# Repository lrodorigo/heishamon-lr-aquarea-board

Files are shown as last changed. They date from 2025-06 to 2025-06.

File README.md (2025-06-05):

# HeishaMon Aquarea
### Alternative Galvanically Isolated Design
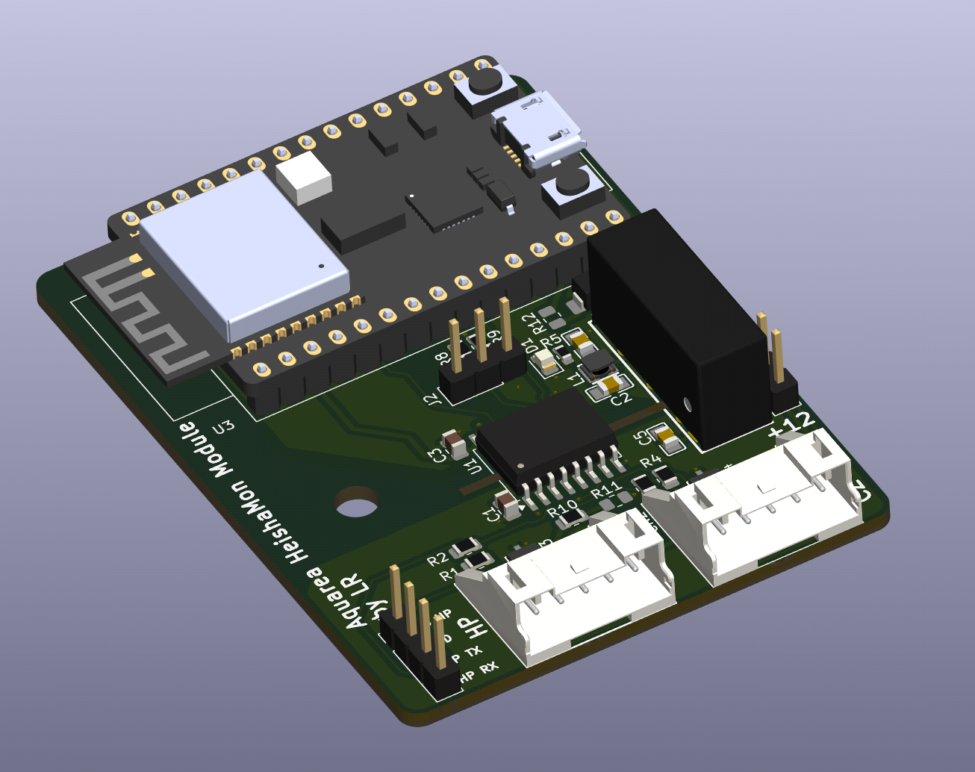
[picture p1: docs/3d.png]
Board Preview


This repository contains an alternative schematic for integrating with Panasonic Aquarea heat pumps using the **HeishaMon** firmware.

## ⚠️ Disclaimer

> This design is **experimental** and has **not yet been tested**.  
> The first hardware version is expected to arrive within a few days.  
> Use at your own risk and feel free to open issues or discussions for feedback and improvements.

## 🛠️ Key Features

- **Galvanically isolated design**  
  Ensures complete electrical isolation from the heat pump for improved safety and reliability.

- **Based on ESP32-C3-DevKitC-02 (official Espressif dev module)**
   
- **Flexible power supply configuration**  
  The board is designed to support different power input scenarios for testing.  
  By default, it uses **12V @ 250mA** to ensure higher available power and better stability.

## 🔧 Firmware Notes

> This board uses different GPIOs than the original HeishaMon design.  
> You **will need to modify the `#define` values** in the firmware source accordingly to match this schematic.  

## 🧩 Usage

The design is tailored for experimenting with various supply options and integration methods, while maintaining full galvanic isolation of the communication lines with the heat pump.

## 📁 Contents

- `export/`: The gerber files

## 📌 Notes

- Intended to be used with HeishaMon firmware (see: https://github.com/Egyras/HeishaMon/)
- Verify jumper settings and isolation components before connecting to the heat pump.

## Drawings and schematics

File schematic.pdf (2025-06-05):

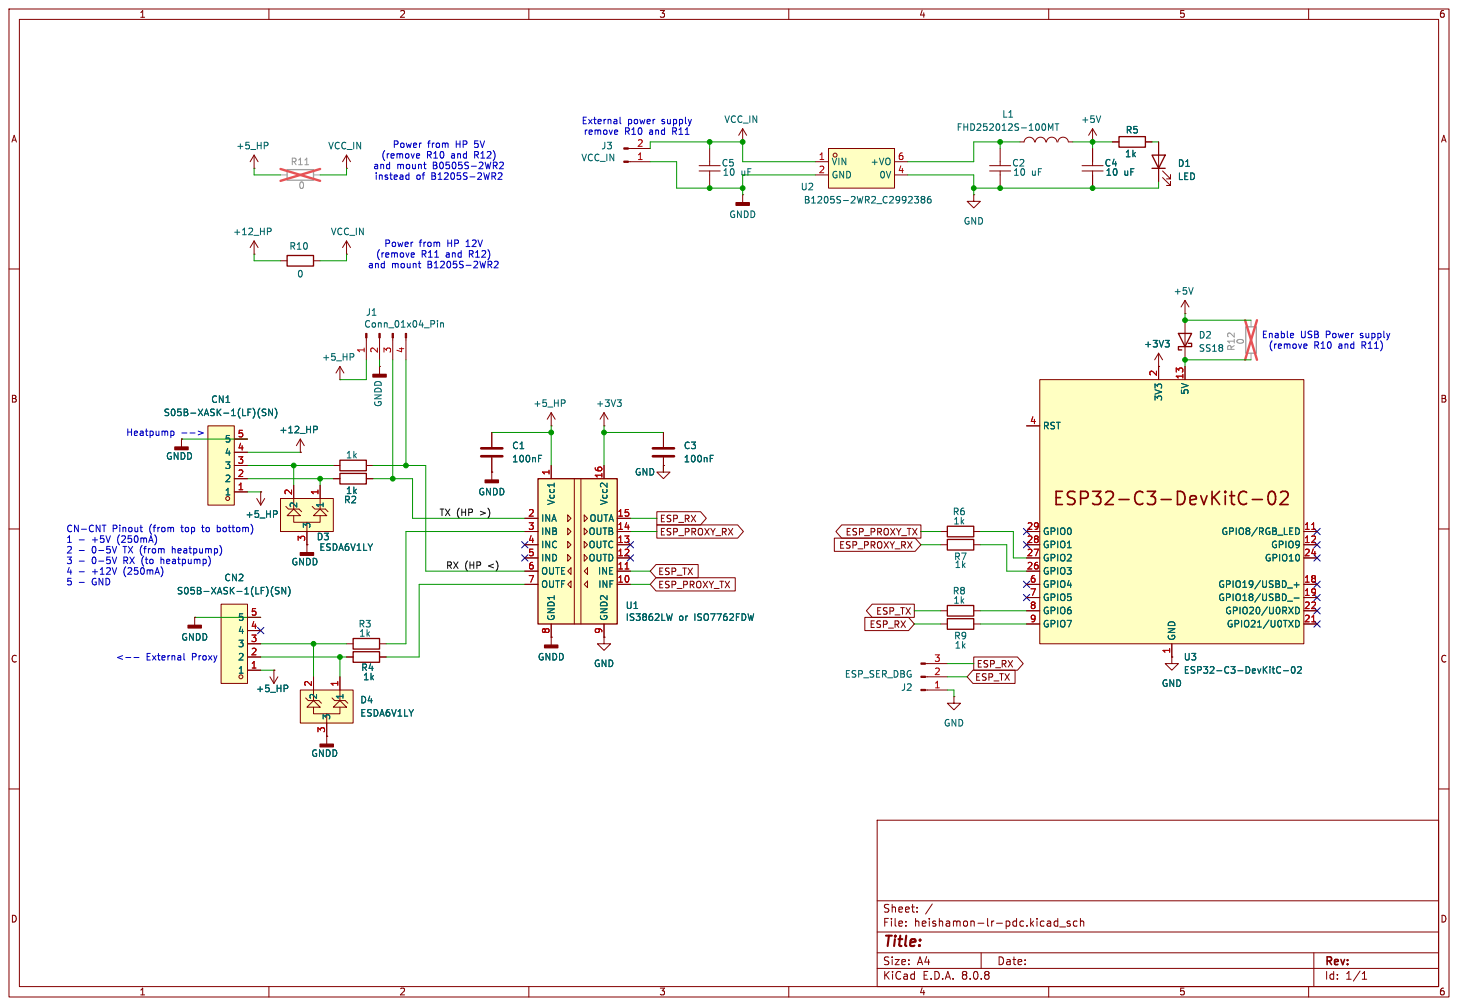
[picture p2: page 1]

(remove R10 and R12) and mount B0505S-2WR2
instead of B1205S-2WR2 Power from HP 12V

5 CN1 S05B-XASK-1(LF)(SN) GNDD

INE 11 OUTD 12 OUTC 13 OUTB 14 OUTA 15 Vcc2 16

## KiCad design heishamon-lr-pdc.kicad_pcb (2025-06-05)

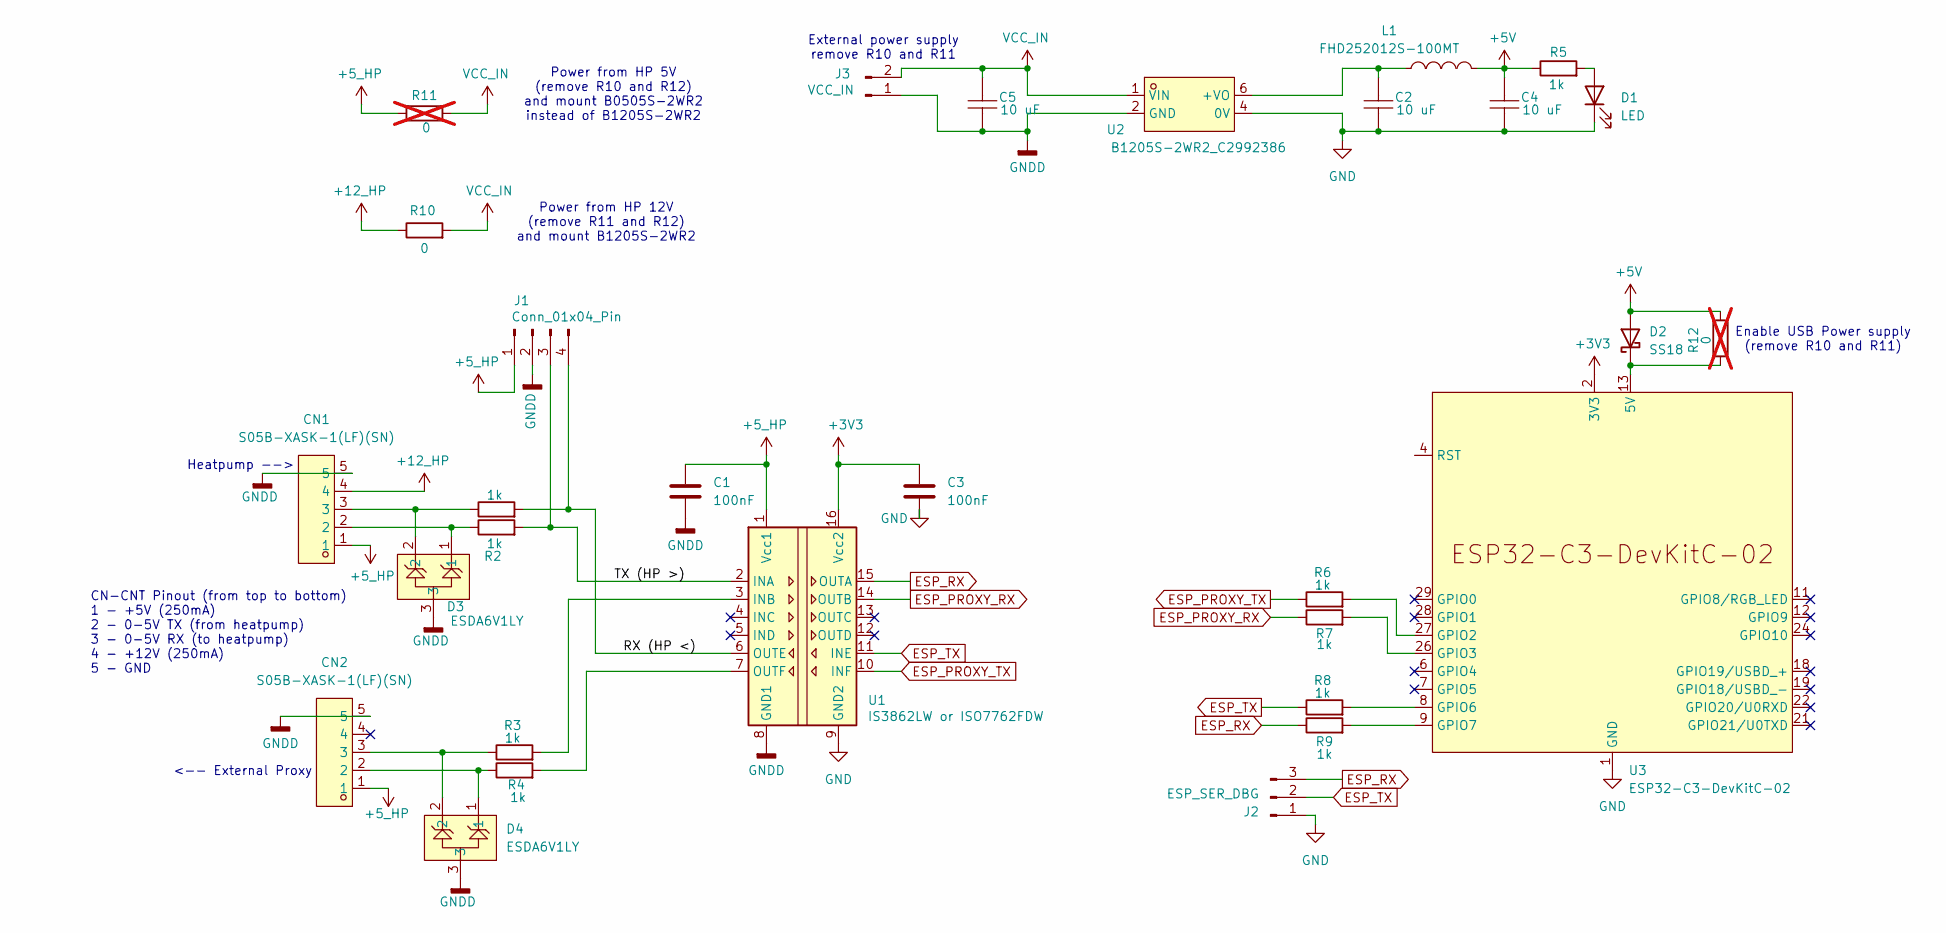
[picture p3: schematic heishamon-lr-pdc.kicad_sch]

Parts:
C1, C3: 100nF; C_0805_2012Metric; LCSC C28233
C2, C4, C5: 10 uF; C0805; LCSC Part C15850
CN1, CN2: S05B-XASK-1(LF)(SN); CONN-TH_S05B-XASK-1-LF-SN; LCSC Part C265396
D1: LED; LED_0805_2012Metric
D2: SS18; D_SMA
D3, D4: ESDA6V1LY; SOT-23-3_L2.9-W1.5-P2.0-LS2.5-BR; LCSC Part C2936094
J1: Conn_01x04_Pin; PinHeader_1x04_P2.54mm_Vertical
J2: ESP_SER_DBG; PinHeader_1x03_P2.54mm_Vertical
J3: VCC_IN; PinHeader_1x02_P2.54mm_Vertical; LCSC C2905434
L1: FHD252012S-100MT; IND-SMD_L2.5-W2.0_FHD252012S-6R8MT; LCSC Part C602018
R1, R2, R3, R4, R6, R7, R8, R9: 1k; R_0805_2012Metric; LCSC C17513
R5: 1k; R_0603_1608Metric
R10: 0; R_0805_2012Metric; LCSC C17513
R11, R12: 0; R_0805_2012Metric; LCSC C17513; not fitted
U1: IS3862LW or ISO7762FDW; SOIC-16W_7.5x10.3mm_P1.27mm; LCSC C20598881
U2: B1205S-2WR2_C2992386; PWRM-TH_IBXX05S-2WR3; LCSC Part C2992386
U3: ESP32-C3-DevKitC-02

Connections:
5V: D2.1 (K), R12.1, U3.13 (5V), U3.14 (5V)
+3V3: C3.1, U1.16 (Vcc2), U3.2 (3V3), U3.3 (3V3)
+5V: C4.2, D2.2 (A), L1.2, R5.1, R12.2
+5_HP: C1.1, CN1.1, CN2.1, J1.1, R11.2, U1.1 (Vcc1)
+12_HP: CN1.4, R10.1
/RX (HP <): J1.4, R1.2, U1.6 (OUTE)
/TX (HP >): J1.3, R2.2, U1.2 (INA)
ESP_PROXY_RX: R7.1, U1.14 (OUTB)
ESP_PROXY_TX: R6.1, U1.10 (INF)
ESP_RX: J2.3, R9.1, U1.15 (OUTA)
ESP_TX: J2.2, R8.1, U1.11 (INE)
GND: C2.1, C3.2, C4.1, D1.1 (K), J2.1, U1.9 (GND2), U2.4 (0V), U3.1 (GND), U3.5 (GND), U3.10 (GND), U3.15 (GND), U3.16 (GND), U3.17 (GND), U3.20 (GND), U3.23 (GND), U3.25 (GND), U3.30 (GND)
GNDD: C1.2, C5.1, CN1.5, CN2.5, D3.3, D4.3, J1.2, J3.1, U1.8 (GND1), U2.2 (GND)
unnamed: CN1.2, D3.1, R2.1
unnamed: CN1.3, D3.2, R1.1
unnamed: CN2.2, D4.1, R4.1
unnamed: CN2.3, D4.2, R3.1
unnamed: D1.2 (A), R5.2
unnamed: R3.2, U1.3 (INB)
unnamed: R4.2, U1.7 (OUTF)
unnamed: C2.2, L1.1, U2.6 (+VO)
unnamed: R6.2, U3.27 (GPIO2)
unnamed: R7.2, U3.26 (GPIO3)
unnamed: R8.2, U3.8 (GPIO6)
unnamed: R9.2, U3.9 (GPIO7)
VCC_IN: C5.2, J3.2, R10.2, R11.1, U2.1 (VIN)

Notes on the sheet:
Power from HP 12V (remove R11 and R12) and mount B1205S-2WR2
CN-CNT Pinout (from top to bottom) 1 - +5V (250mA) 2 - 0-5V TX (from heatpump) 3 - 0-5V RX (to heatpump) 4 - +12V (250mA) 5 - GND
Heatpump -->
<-- External Proxy
Enable USB Power supply (remove R10 and R11)
External power supply remove R10 and R11
Power from HP 5V (remove R10 and R12) and mount B0505S-2WR2 instead of B1205S-2WR2

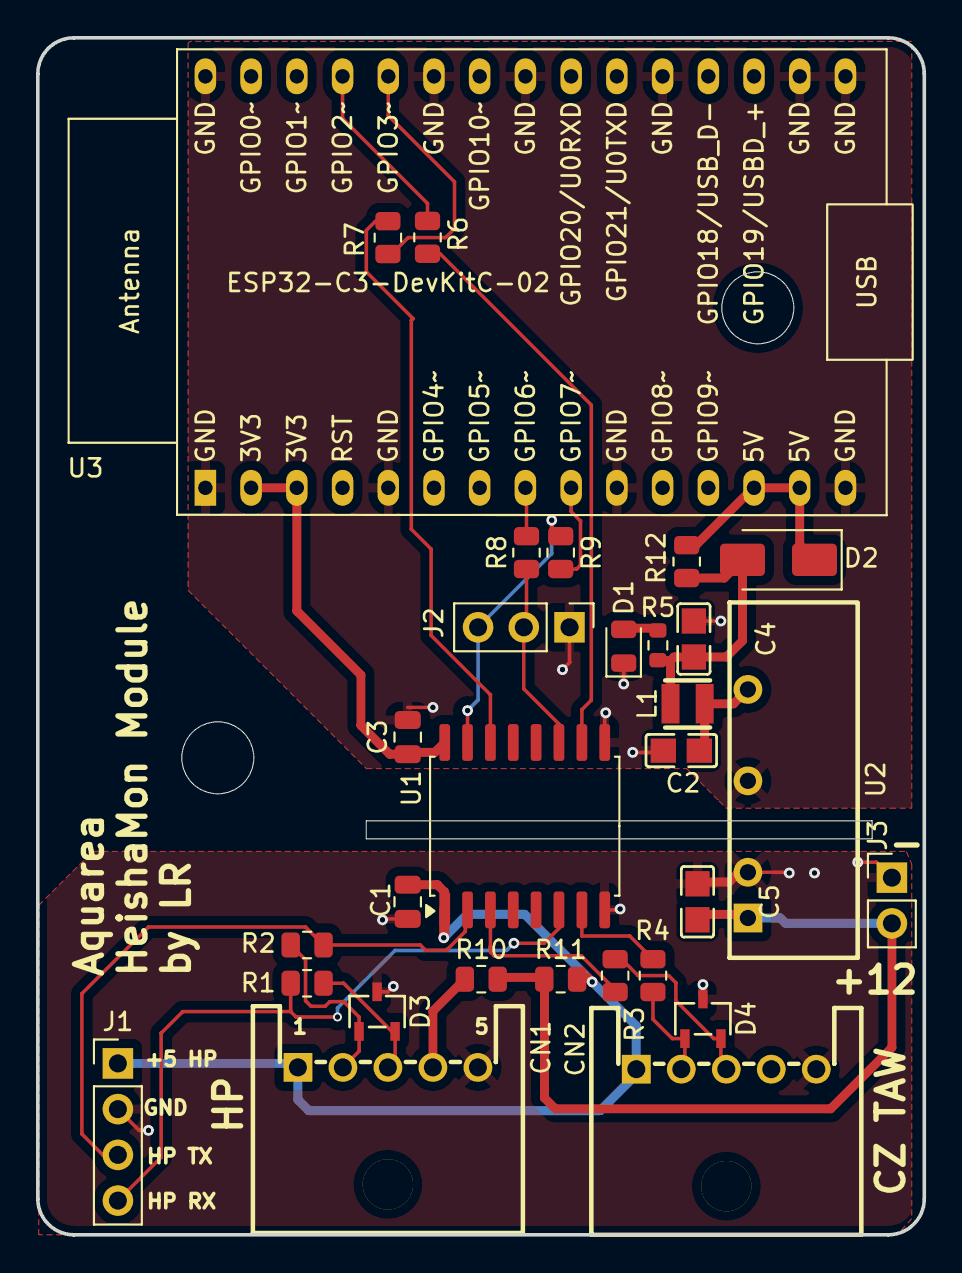
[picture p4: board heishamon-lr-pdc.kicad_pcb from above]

Board: 2 copper layers, 49.2 x 66.5 mm, 30 parts (0 on the bottom side), 26 nets.
